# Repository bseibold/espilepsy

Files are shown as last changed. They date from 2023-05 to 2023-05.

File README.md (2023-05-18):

ESPilepsy
=========

A small ESP32 board to drive 2 LED strips, intended to be used with [WLED](https://kno.wled.ge/)

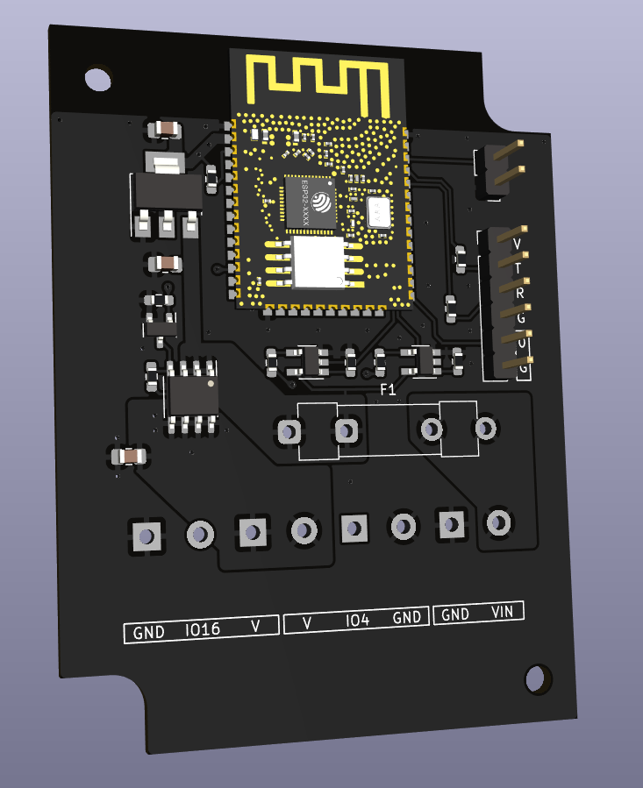
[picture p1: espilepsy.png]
A rendered image of the PCB

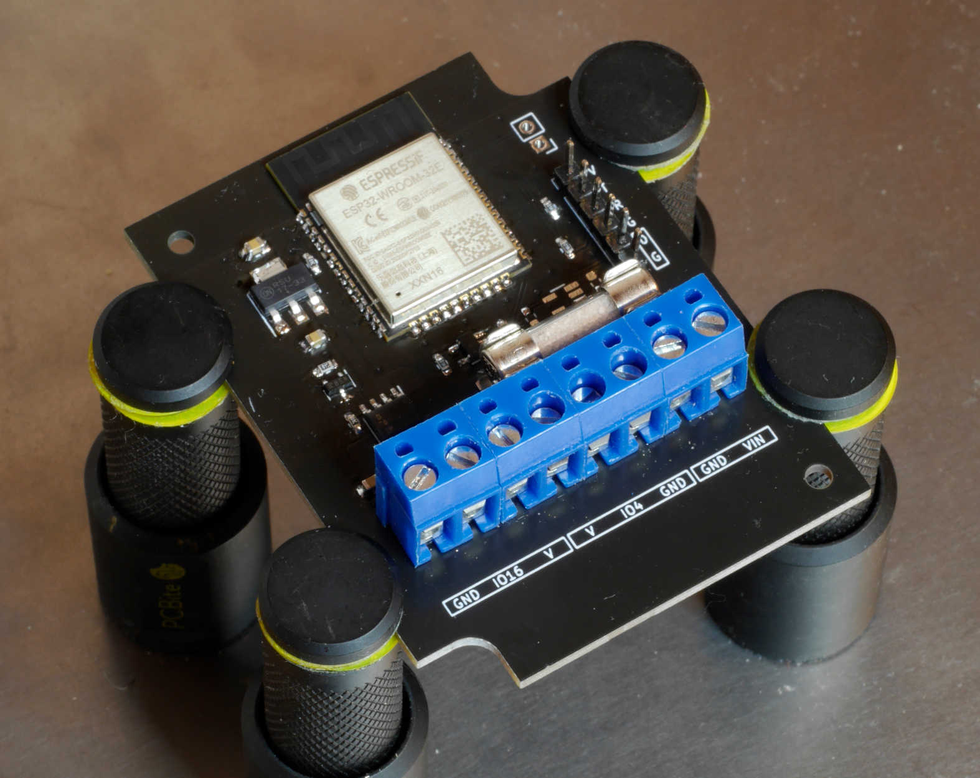
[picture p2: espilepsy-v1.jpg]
A photo of the assembled PCB


## Status

Assembled, initial testing done

## Features and non-features

 - Only 5V LED strips
 - Works with at least 6A current
 - LEDs can be powered down via FET (no relay)
 - Normal fuse, no poly-fuse
 - No IR receiver
 - No reverse voltage protection
 - No built-in USB-to-UART

## Design constraints

 - Design rules compatible with [JLCPCB](https://jlcpcb.com/) (because it's cheap)
 - Use only parts available at [Reichelt](https://www.reichelt.de/) (because it's convenient)
 - If possible, use widely-used parts
 - SMD parts no smaller than 0603
 - pin spacing at least about 1mm (SOT23-5 is about the smallest acceptable)

## Bill of materials

(Work in progress)

### ESP32

All ESP32-WROOM-32x modules seem to be pin-compatible.

Reichelt:
 - [ESP32-WROOM-32D](https://www.reichelt.de/wifi-smd-modul-esp32-d0wd-4-mb-spi-3-3-v-18-x-25-5-x-3-2-mm-esp32wroom32d-p300012.html)
 - [ESP32-WROOM-32E-N4](https://www.reichelt.de/wifi-smd-modul-esp32-d0wd-v3-16-mb-spi-3-3-v-18-x-25-5-x-3-1-esp32wroom32e16-p300025.html)
 - [ESP32-WROOM-32E-N8](https://www.reichelt.de/wifi-modul-802-11-bt-2-4-2-5ghz-150mb-s-esp32wroom32e8-p311740.html)
 - [ESP32-WROOM-32E-N16](https://www.reichelt.de/wifi-smd-modul-esp32-d0wd-v3-16-mb-spi-3-3-v-18-x-25-5-x-3-1-esp32wroom32e16-p300025.html)

### High-side switch

There are lots of parts that can be used here

 - must be enhancement-type p-FET
 - SO-8 package
 - Vg(th) should be low enough that the FET is full on at ~4.5V
 
Reichelt: 
 - [AO4407A](https://www.reichelt.de/mosfet-p-kanal-30-v-12-a-rds-on-0-0085-ohm-so-8-ao-4407a-p166495.html)
 - [IRF9310](https://www.reichelt.de/mosfet-p-ch-30v-20a-2-5w-so-8-irf-9310-p132127.html)
 - [TSM160P02CS](https://www.reichelt.de/mosfet-p-ch-20v-11a-0-016r-so8-tsm160p02cs-p254930.html)

### Level Shifter

One-gate versions of the 74xx125 will fit, but will require the pull-down resistor on pin 1 to be mounted. The selected variant must be compatible with LVCMOS input voltages, so 74HCT, 74AHCT, 74VHCT, etc.

Reichelt:
 - [M74VHC1GT50](https://www.reichelt.de/buffer-cmos-1-65--5-5-v-sot-23-5-m74vhc1gt50dtt1g-p219278.html)

### Enclosure

Reichelt:
 - [4U32100603006](https://www.reichelt.de/industriegehaeuse-76-x-59-x-28-mm-ip54-schwarz-4u32100603006-p324273.html)

### Screw Terminals

AKL073 from Reichelt won't fit into the enclosure.

Reichelt:
 - [AKL 101-02](https://www.reichelt.de/anschlussklemme-2-pol-2-mm-rm-5-08-akl-101-02-p36605.html)
 - [CTB0509-2](https://www.reichelt.de/loetbare-schraubklemme-2-pol-rm-5-08-mm-90--ctb0509-2-p292701.html)

## Similar projects

If this doesn't fit your needs, check out these other cool boards:

 - [Yet Another WLED Controller](https://github.com/lizardsystems/yawl-controller)

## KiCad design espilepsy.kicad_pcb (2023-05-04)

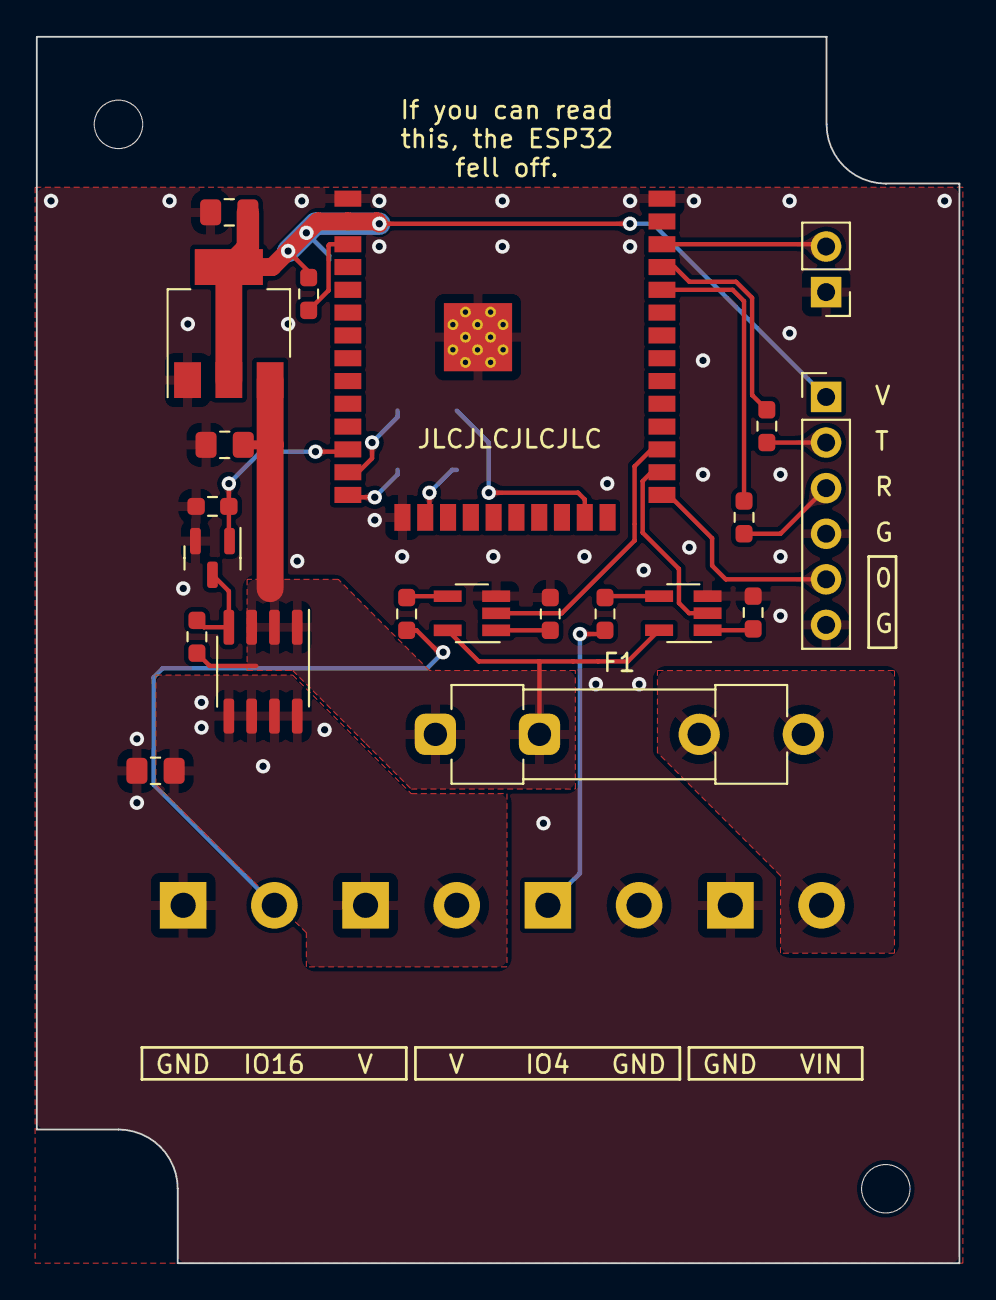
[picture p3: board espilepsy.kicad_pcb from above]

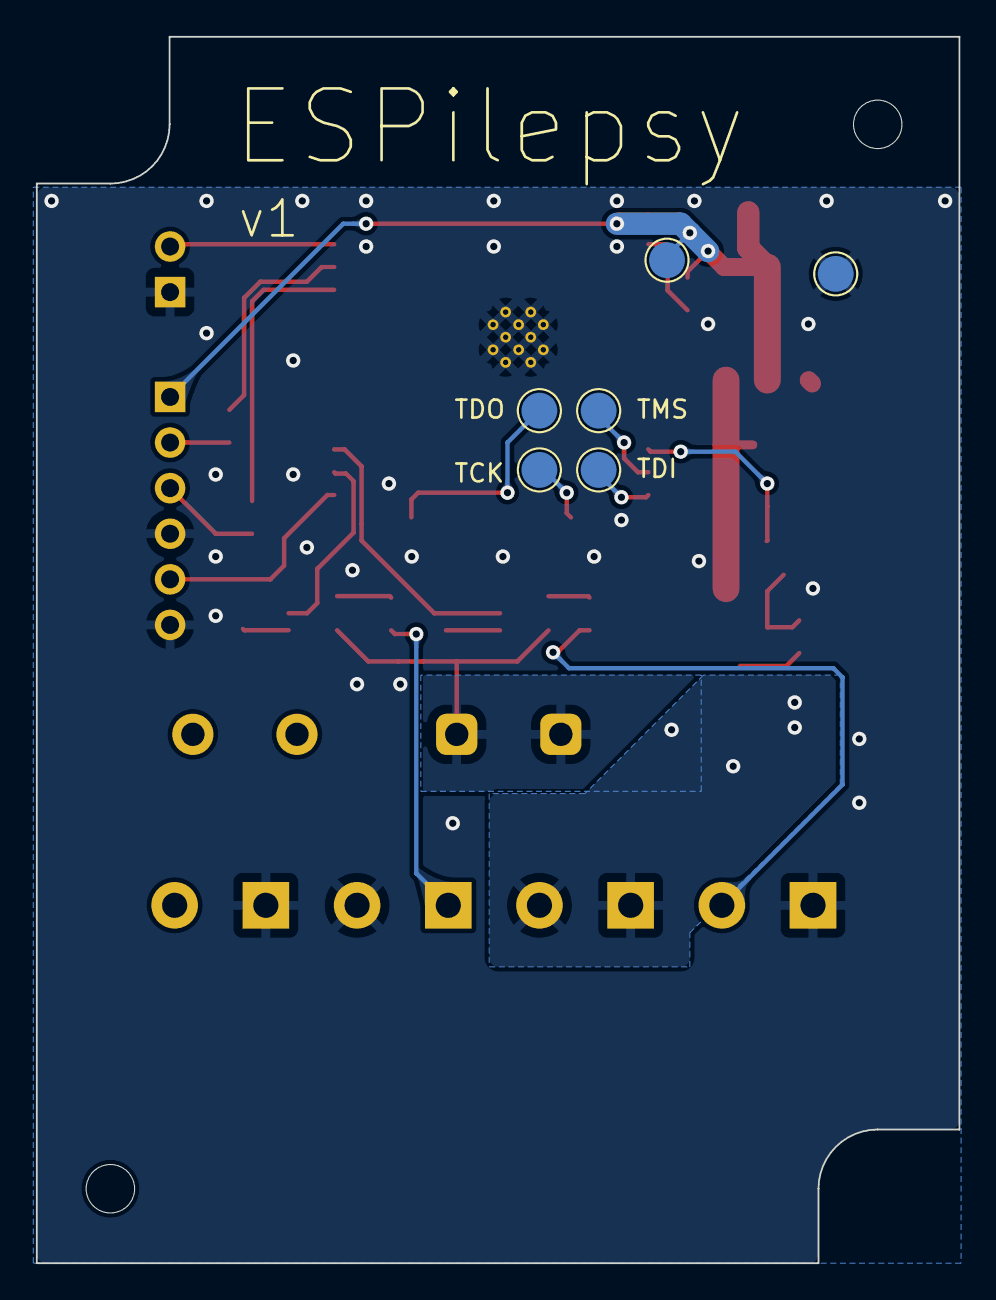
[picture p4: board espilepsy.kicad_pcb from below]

Board: 2 copper layers, 51.4 x 68.3 mm, 33 parts (6 on the bottom side), 26 nets.

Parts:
C1, C2, C3: 10u; C_0805_2012Metric_Pad1.18x1.45mm_HandSolder
F1: Fuse_Small; Fuseholder_Clip-5x20mm_Littelfuse_520_Inline_P20.50x5.80mm_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
H1, H2: MountingHole; MountingHole_2.7mm_M2.5
J1: Conn_01x06; PinHeader_1x06_P2.54mm_Vertical
J2, J3, J4, J5: Screw_Terminal_01x02; TerminalBlock_MetzConnect_Type073_RT02602HBLU_1x02_P5.08mm_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
J6: Conn_01x02_Pin; PinHeader_1x02_P2.54mm_Vertical
Q1: BSS138; SOT-23
Q2: IRF9310; SOIC-8_3.9x4.9mm_P1.27mm
R1, R4, R5, R8, R9: 10k; R_0603_1608Metric_Pad0.98x0.95mm_HandSolder
R6, R7, R10, R11: 100; R_0603_1608Metric_Pad0.98x0.95mm_HandSolder
TP1, TP2, TP3, TP4, TP5, TP6: TestPoint; TestPoint_Pad_D2.0mm
U1: NCP1117-3.3_SOT223; SOT-223-3_TabPin2
U2, U4: M74VHC1GT50; SOT-23-5_HandSoldering
U3: ESP32-WROOM-32D; ESP32-WROOM-32D-JLCPCB

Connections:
+3.3V: C1.1, J1.1, R1.2, TP1.1, U1.2 (VO), U3.2 (VDD)
+5V: C2.1, F1.1, Q2.1 (S), Q2.2 (S), Q2.3 (S), R5.1, U1.3 (VI), U2.5 (VCC), U4.5 (VCC)
/BTN_1: J6.2, U3.36 (IO22)
/EN: R1.1, U3.3 (EN)
/IO0: J1.5, U3.25 (IO0)
/LED_5V: C3.1, J3.1, J3.2, Q2.5 (D), Q2.6 (D), Q2.7 (D), Q2.8 (D)
/LED_DATA_0: U3.27 (IO16), U4.2
/LED_DATA_0_OUT: J2.2, R7.2
/LED_DATA_1: U2.2, U3.26 (IO4)
/LED_DATA_1_OUT: J4.1, R6.2
/LED_POWER: Q1.1 (G), R4.1, U3.12 (IO27)
/TCK: TP4.1, U3.16 (IO13)
/TDI: TP3.1, U3.14 (IO12)
/TDO: TP5.1, U3.23 (IO15)
/TMS: TP2.1, U3.13 (IO14)
/UART_RX: J1.3, R10.2
/UART_TX: J1.2, R11.2
/VIN: F1.2, J5.2
GND: C1.2, C2.2, C3.2, J1.4, J1.6, J2.1, J4.2, J5.1, J6.1, Q1.2 (S), R4.2, R8.2, R9.2, TP6.1, U1.1 (ADJ), U2.3 (GND), U3.1 (GND), U3.15 (GND), U3.38 (GND), U3.39 (GND), U4.3 (GND)
unnamed: Q1.3 (D), Q2.4 (G), R5.2
unnamed: R6.1, U2.4
unnamed: R7.1, U4.4
unnamed: R8.1, U4.1
unnamed: R9.1, U2.1
unnamed: R10.1, U3.34 (RXD0/IO3)
unnamed: R11.1, U3.35 (TXD0/IO1)

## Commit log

2023-04-20 First draft
    [espilepsy.kicad_pcb, espilepsy.kicad_sch, led_driver.kicad_sch]
2023-05-04 Build v1
    [espilepsy-B_Cu.gbl, espilepsy-B_Mask.gbs, espilepsy-B_Paste.gbp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]
